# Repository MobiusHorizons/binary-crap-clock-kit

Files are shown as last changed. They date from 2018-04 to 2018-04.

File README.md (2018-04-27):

This is a fairly crap clock kit made with CMOS logic, it is a fairly simple design and has the unique feature of being both difficult to read and difficult to set the time! Consider it a curiosity rather than a real timepiece, I cannot make any absolute guarantees about its accuracy but it is fairly good.

I made it as a challenge to myself more than anything else, an exercise in learning about CMOS logic and making my first kit.

clock in action

It runs down to about 2.7-3v (0.5mA with LEDs and ~6µA without the LEDs running) and up to 6v and consumes very little current running at lower voltages. In fact, you could run it for years on 2AA batteries with the LEDs disabled. At 3v the LEDs are fairly dim but at 5v they will dazzle you, choose your poison.

I haven't included extensive instructions, it should be fairly self-explanatory... that said, I mess stuff up all the time. So with that in mind, here is a video of me building it. I realise this could be a bit of a slog to watch so feel free to just wing it.

<iframe class="embed-responsive-item" src="https://www.youtube.com/embed/5j2Psmb9NmE?feature=oembed&amp;wmode=transparent"></iframe>

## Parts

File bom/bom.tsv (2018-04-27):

References | Qty | Description | Manufacturer | Part Number | Digikey | Mouser | RS | Newark | Farnell
S2, S3, S5 | 3 | OMRON SWITCH B3F-10XX | Omron | B3F-1000 | SW400-ND | 653-B3F-1000
LED1, LED2, LED3, LED4, LED5, LED6, LED7, LED8, LED9, LED10, LED11, LED13, LED14, LED17, LED18, LED19, LED20, LED22, LED23, LED24 | 20 | LED | Cree | C513A-WSS-CX0Z0231 | C513A-WSS-CX0Z0231-ND | 941-C513AWSSCX0Z0231
C3, C4, C5, C6, C7, C8 | 6 | Through-hole capacitor 100nf | KEMET | C322C104K5R5TA | 399-4329-ND | 80-C322C104K5R
R24, R25, R26, R27, R28 | 5 | 10k RESISTOR 0805 | Bourns Inc. | CR0805-FX-1002ELF | CR0805-FX-1002ELFCT-ND | 652-CR0805FX-1002ELF
C10 | 1 | Through-hole capacitor 10uf | Panasonic | ECE-A1EKA100 | P813-ND | 667-ECE-A1EKA100I
D1, D2, D3, D4 | 4 | 1.0A SCHOTTKY BARRIER RECTIFIER | Diodes Incorporated | 1N5817-B | 1N5817-BDI-ND | 583-1N5817-B
Q1 | 1 | CRYSTAL 32.768 khz | Abracon LLC | AB38T-32.768KHZ | 535-9034-ND | 815-AB38T-32.768KHZ
R3 | 1 | RESISTOR, 330k | Susumu | RR0816P-334-D | RR08P330KDCT-ND | 754-RR0816P-334D
C1, C2 | 2 | CAPACITOR, 33pf | Vishay BC Components | K330J15C0GF5TH5 | BC1036CT-ND | 594-K330J15C0GF5TH5
IC11 | 1 | Dual JK FLIP FLOP 4027D | Texas Instruments | CD4027BM96 | 296-31493-1-ND | 595-CD4027BM96
IC10 | 1 | 14-stage binary/ripple COUNTER 4060 | Texas Instruments | CD4060BM96 | 296-31513-1-ND | 595-CD4060BM96
IC12 | 1 | Quad 2-input AND 4081 | Texas Instruments | CD4081BM96 | 296-25955-1-ND | 595-CD4081BM96
IC1, IC3, IC4, IC6, IC7, IC8 | 6 | BCD up down COUNTER 4510 | Texas Instruments | CD4510BNSR | 296-14152-6-ND | 595-CD4510BNSR
R4, R5, R6, R7, R8, R9, R10, R11, R12, R13, R14, R15, R16, R17, R18, R19, R20, R21, R22, R23 | 20 | RESISTOR, 470 | Stackpole Electronics Inc. | RMCF0805JG470R | RMCF0805JG470RCT-ND | 652-CR0805JW-471ELF
R1, R2 | 2 | RESISTOR, 6.8M | Vishay Dale | CRCW08056M80FKEA | 541-6.80MCCT-ND | 71-CRCW08056M80FKEA

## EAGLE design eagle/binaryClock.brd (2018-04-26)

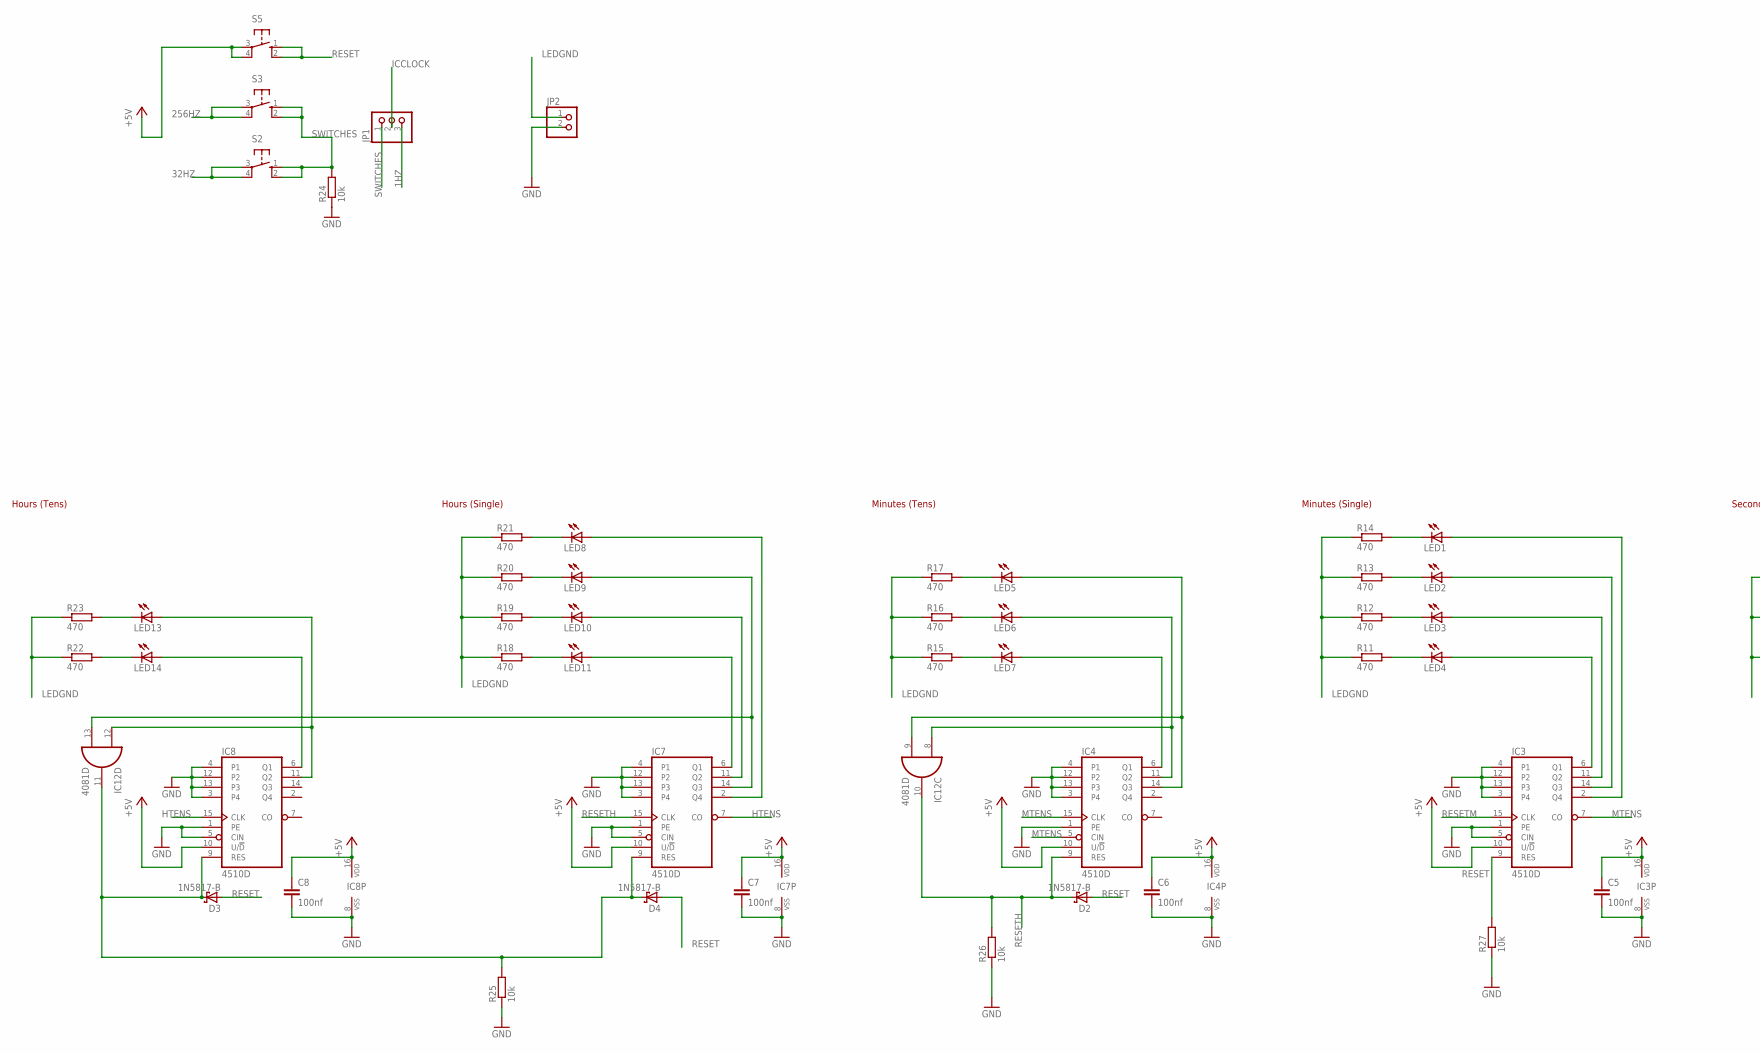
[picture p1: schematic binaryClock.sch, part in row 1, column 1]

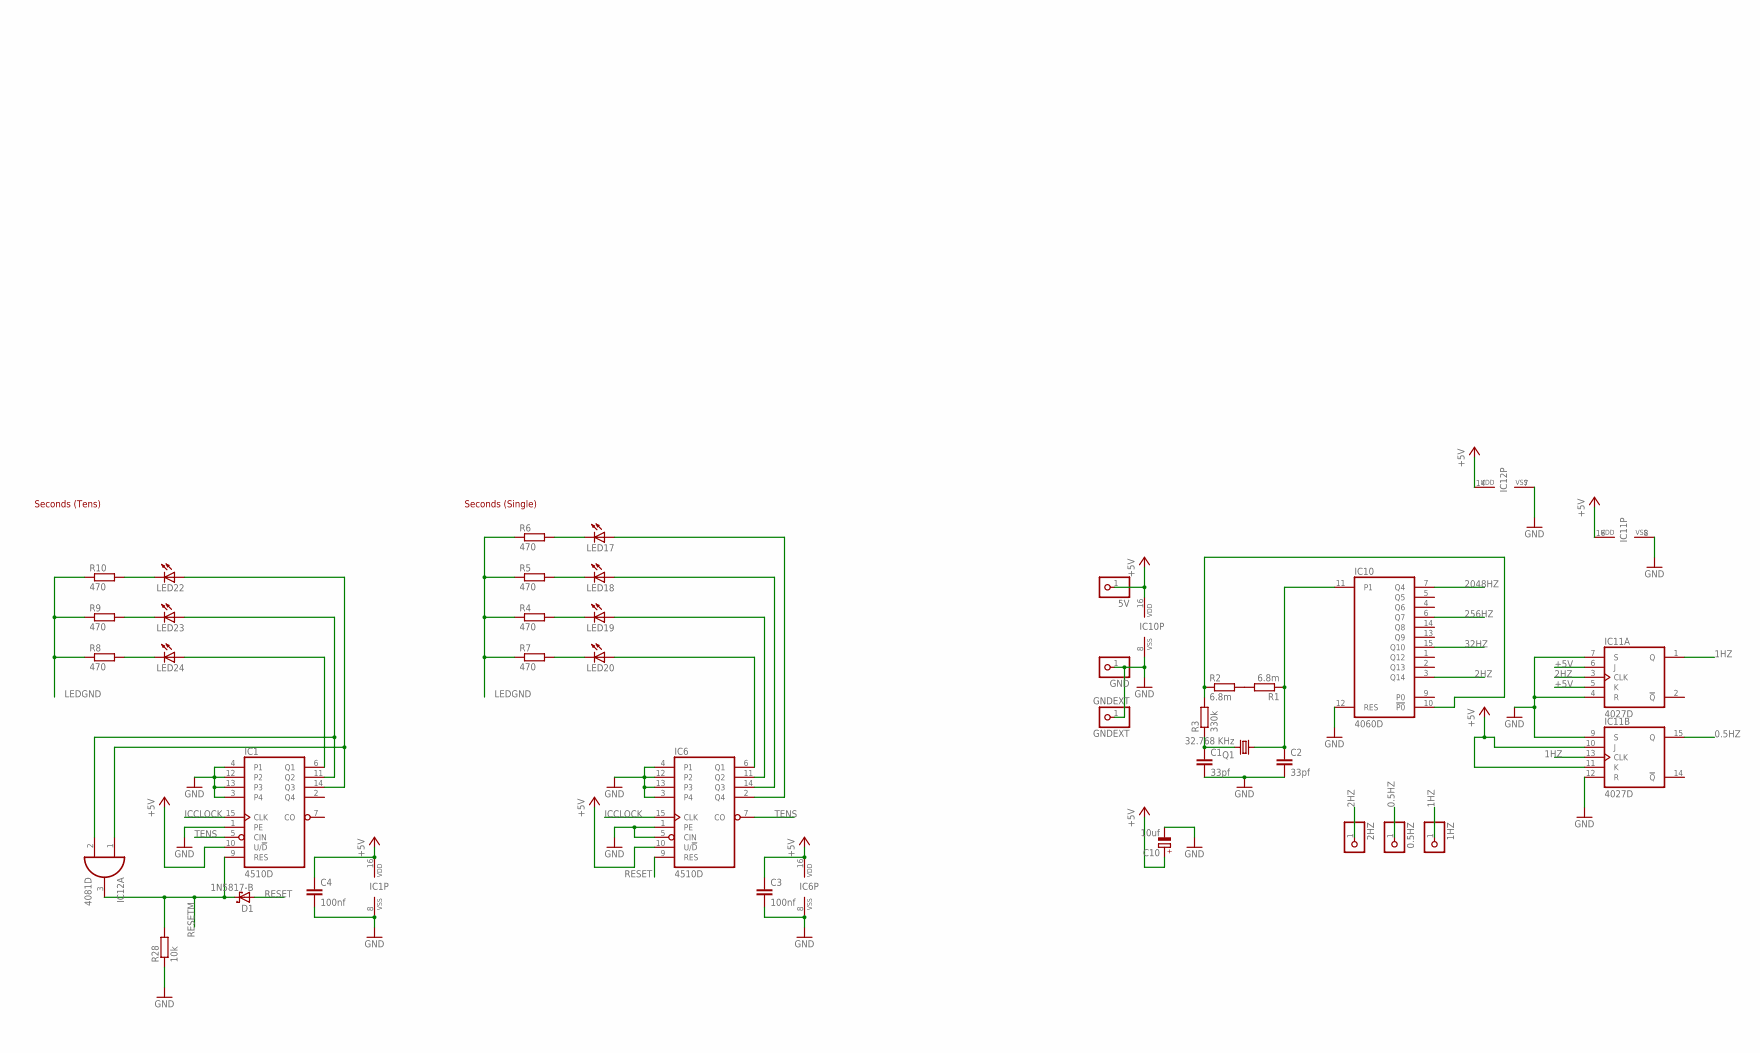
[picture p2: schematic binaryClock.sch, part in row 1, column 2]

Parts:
0.5HZ, 1HZ, 2HZ, 5V: PINHD-1X1; 1X01
C1, C2: 33pf; C025-030X050
C3, C4, C5, C6, C7, C8: 100nf; C025-030X050
C10: 10uf; E2,5-5
D1, D2, D3, D4: 1N5817-B; DO41-7.6
GND: PINHD-1X1; 1X01
GNDEXT: GNDEXT; 1X01
IC1, IC3, IC4, IC6, IC7, IC8: 4510D; SO16
IC10: 4060D; SO16
IC11: 4027D; SO16
IC12: 4081D; SO14
JP1: PINHD-1X3; 1X03
JP2: PINHD-1X2; 1X02
LED1, LED2, LED3, LED4, LED5, LED6, LED7, LED8, LED9, LED10, LED11, LED13, LED14, LED17, LED18, LED19, LED20, LED22, LED23, LED24: LED5MM
Q1: 32.768 KHz; TC26H
R1, R2: 6.8m; R0805
R3: 330k; R0805
R4, R5, R6, R7, R8, R9, R10, R11, R12, R13, R14, R15, R16, R17, R18, R19, R20, R21, R22, R23: 470; R0805
R24, R25, R26, R27, R28: 10k; R0805
S2, S3, S5: 10-XX; B3F-10XX

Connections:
0.5HZ: 0.5HZ.1, IC11.15 (Q)
1HZ: 1HZ.1, IC11.1 (Q), IC11.13 (CLK), JP1.3
2HZ: 2HZ.1, IC10.3 (Q14), IC11.3 (CLK)
32HZ: IC10.15 (Q10), S2.3, S2.4 (P1)
256HZ: IC10.6 (Q7), S3.3, S3.4 (P1)
2048HZ: IC10.7 (Q4)
+5V: 5V.1, C3.1, C4.1, C5.1, C6.1, C7.1, C8.1, C10.+, IC1.10 (U/!D), IC1.16 (VDD), IC3.10 (U/!D), IC3.16 (VDD), IC4.10 (U/!D), IC4.16 (VDD), IC6.10 (U/!D), IC6.16 (VDD), IC7.10 (U/!D), IC7.16 (VDD), IC8.10 (U/!D), IC8.16 (VDD), IC10.16 (VDD), IC11.5 (K), IC11.6 (J), IC11.10 (J), IC11.11 (K), IC11.16 (VDD), IC12.14 (VDD), S5.3, S5.4 (P1)
GND: C1.2, C2.2, C3.2, C4.2, C5.2, C6.2, C7.2, C8.2, C10.-, GND.1, GNDEXT.1, IC1.1 (PE), IC1.3 (P4), IC1.4 (P1), IC1.8 (VSS), IC1.12 (P2), IC1.13 (P3), IC3.1 (PE), IC3.3 (P4), IC3.4 (P1), IC3.5 (CIN), IC3.8 (VSS), IC3.12 (P2), IC3.13 (P3), IC4.1 (PE), IC4.3 (P4), IC4.4 (P1), IC4.8 (VSS), IC4.12 (P2), IC4.13 (P3), IC6.1 (PE), IC6.3 (P4), IC6.4 (P1), IC6.5 (CIN), IC6.8 (VSS), IC6.12 (P2), IC6.13 (P3), IC7.1 (PE), IC7.3 (P4), IC7.4 (P1), IC7.5 (CIN), IC7.8 (VSS), IC7.12 (P2), IC7.13 (P3), IC8.1 (PE), IC8.3 (P4), IC8.4 (P1), IC8.5 (CIN), IC8.8 (VSS), IC8.12 (P2), IC8.13 (P3), IC10.8 (VSS), IC10.12 (RES), IC11.4 (R), IC11.7 (S), IC11.8 (VSS), IC11.9 (S), IC11.12 (R), IC12.7 (VSS), JP2.2, R24.1, R25.1, R26.1, R27.1, R28.1
HTENS: IC7.7 (CO), IC8.15 (CLK)
ICCLOCK: IC1.15 (CLK), IC6.15 (CLK), JP1.2
LEDGND: JP2.1, R4.1, R5.1, R6.1, R7.1, R8.1, R9.1, R10.1, R11.1, R12.1, R13.1, R14.1, R15.1, R16.1, R17.1, R18.1, R19.1, R20.1, R21.1, R22.1, R23.1
MTENS: IC3.7 (CO), IC4.5 (CIN), IC4.15 (CLK)
unnamed: IC6.6 (Q1), LED20.A
unnamed: IC6.11 (Q2), LED19.A
unnamed: R1.2, R2.2
unnamed: C1.1, Q1.2, R3.1
unnamed: IC10.10 (!P0), R2.1, R3.2
unnamed: C2.1, IC10.11 (P1), Q1.1, R1.1
unnamed: IC6.14 (Q3), LED18.A
unnamed: IC6.2 (Q4), LED17.A
unnamed: LED17.K (C), R6.2
unnamed: LED18.K (C), R5.2
unnamed: LED19.K (C), R4.2
unnamed: LED20.K (C), R7.2
unnamed: IC1.6 (Q1), LED24.A
unnamed: IC1.11 (Q2), IC12.2 (I1), LED23.A
unnamed: IC1.14 (Q3), IC12.1 (I0), LED22.A
unnamed: D3.C, D4.C, IC7.9 (RES), IC8.9 (RES), IC12.11 (O), R25.2
unnamed: IC7.6 (Q1), LED11.A
unnamed: LED22.K (C), R10.2
unnamed: LED23.K (C), R9.2
unnamed: LED24.K (C), R8.2
unnamed: IC7.11 (Q2), LED10.A
unnamed: IC3.6 (Q1), LED4.A
unnamed: IC3.11 (Q2), LED3.A
unnamed: IC3.14 (Q3), LED2.A
unnamed: IC3.2 (Q4), LED1.A
unnamed: LED1.K (C), R14.2
unnamed: LED2.K (C), R13.2
unnamed: LED3.K (C), R12.2
unnamed: LED4.K (C), R11.2
unnamed: IC4.6 (Q1), LED7.A
unnamed: IC4.11 (Q2), IC12.8 (I0), LED6.A
unnamed: IC4.14 (Q3), IC12.9 (I1), LED5.A
unnamed: LED5.K (C), R17.2
unnamed: LED6.K (C), R16.2
unnamed: LED7.K (C), R15.2
unnamed: IC7.14 (Q3), IC12.13 (I1), LED9.A
unnamed: IC7.2 (Q4), LED8.A
unnamed: LED8.K (C), R21.2
unnamed: LED9.K (C), R20.2
unnamed: LED10.K (C), R19.2
unnamed: LED11.K (C), R18.2
unnamed: IC8.6 (Q1), LED14.A
unnamed: IC8.11 (Q2), IC12.12 (I0), LED13.A
unnamed: LED13.K (C), R23.2
unnamed: LED14.K (C), R22.2
RESET: D1.A, D2.A, D3.A, D4.A, IC3.9 (RES), IC6.9 (RES), R27.2, S5.1 (S), S5.2 (S1)
RESETH: D2.C, IC4.9 (RES), IC7.15 (CLK), IC12.10 (O), R26.2
RESETM: D1.C, IC1.9 (RES), IC3.15 (CLK), IC12.3 (O), R28.2
SWITCHES: JP1.1, R24.2, S2.1 (S), S2.2 (S1), S3.1 (S), S3.2 (S1)
TENS: IC1.5 (CIN), IC6.7 (CO)

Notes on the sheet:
Seconds (Single)
Seconds (Tens)
Minutes (Single)
Minutes (Tens)
Hours (Single)
Hours (Tens)

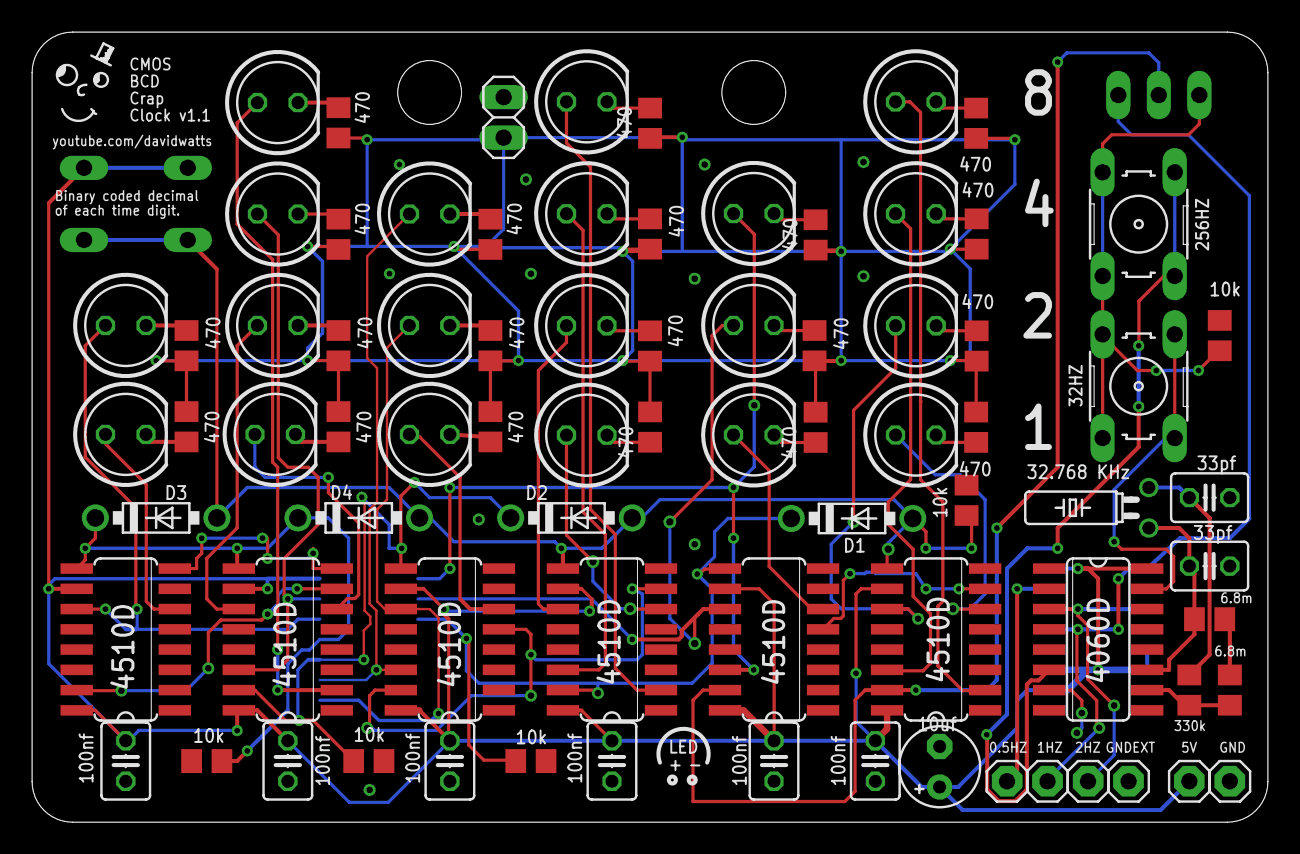
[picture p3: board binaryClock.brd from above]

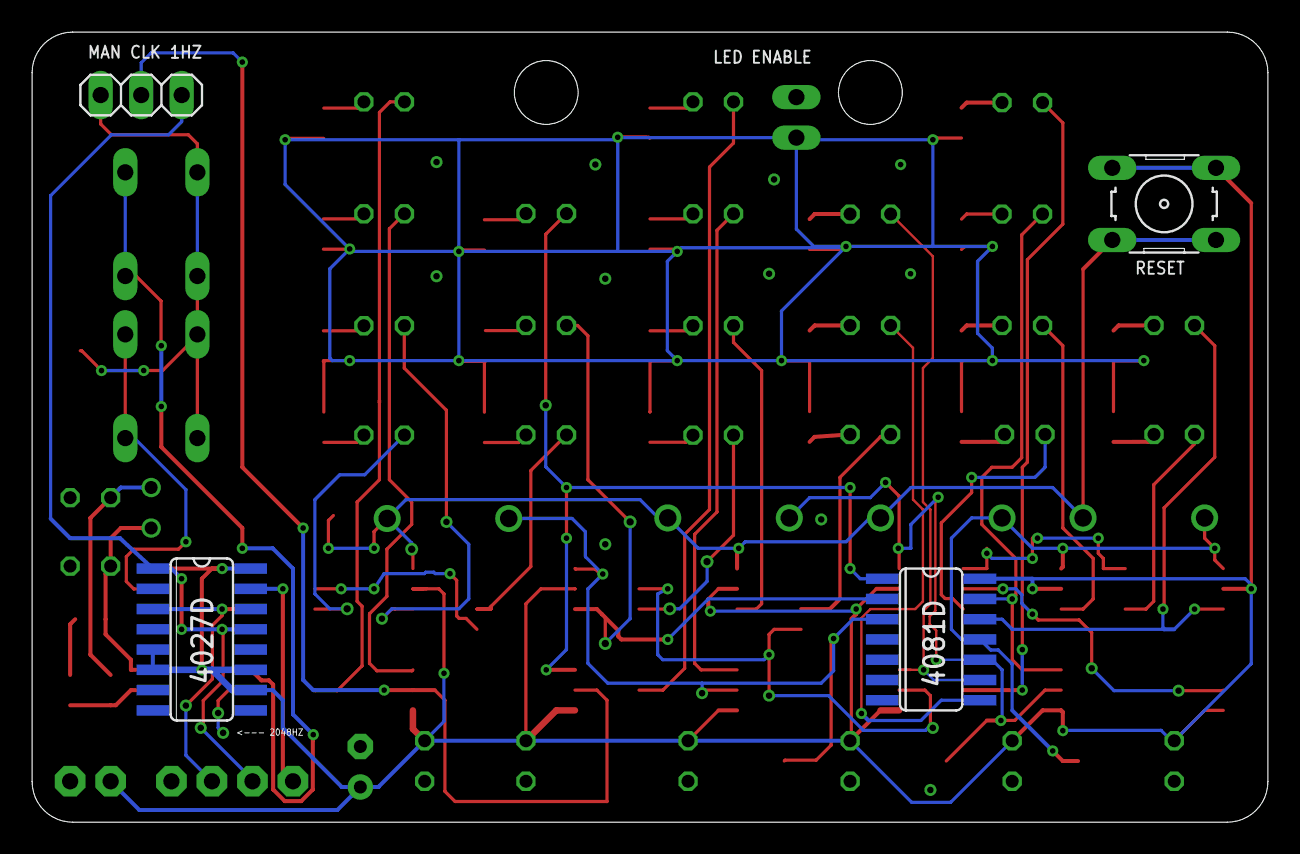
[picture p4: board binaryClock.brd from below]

Board: 2 copper layers, 77.5 x 49.5 mm, 82 parts (4 on the bottom side), 61 nets.

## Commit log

2018-04-26 Initial Commit with WIP BOM
    [binaryClock.brd, binaryClock.sch, bom.tsv]
2018-04-27 Updated bom
    [bom.tsv]
2018-04-27 updated bom and added drill file
    [bom.tsv]
